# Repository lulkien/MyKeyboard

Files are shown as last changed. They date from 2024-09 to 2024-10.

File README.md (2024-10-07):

# My Custom Mechanical Keyboard

This is the design for my custom TLK, where I'm gonna make my own keyboard from scratch with hotswap controller.

(I have no idea why I'm doing this but it's kinda cool)

## Todo:

- [x] PCB Design (Kicad 8)
- [x] Case Design (OpenSCAD)
- [x] Firmware (use Rust)

## References:

- [Joe Scotto's guide for the PCB design](https://www.youtube.com/watch?v=7LyziNdFlew&list=PLBD2IS_t_iWZDMdG_ZF57x9Ebm3kxKqxF) (recommend to watch this playlist first)

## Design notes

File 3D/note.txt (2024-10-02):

pcb width: 295.275mm
pcb height: 152.4mm

plate to pcb: 3.5mm

plate slot:
    width: 152.4mm
    height: 1.5mm
    depth: 2mm

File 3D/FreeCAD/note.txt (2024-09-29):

Plate (
    geometry: [
        Rectangle (
            name: "USB in header",
            top: (44.7, 143.8),
            width: 5.8,
            height: 13.3,
        ),
        Rectangle (
            name: "Pico",
            top: (120.6, 148.7),
            width: 54.1,
            height: 24,1,
        ),
        Rectangle (
            name: "screen header",
            top: (253.3, 145.8),
            width: 13.3,
            header: 5.8,
        ),
    ],
)

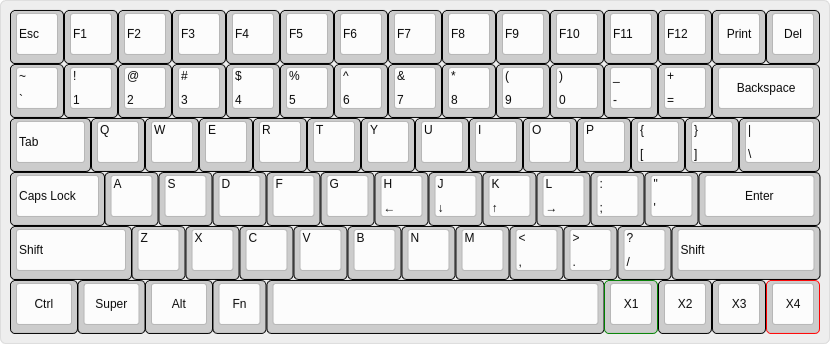
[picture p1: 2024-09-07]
layout/keyboard-layout.png

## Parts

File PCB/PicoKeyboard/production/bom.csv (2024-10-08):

Designator | Footprint | Quantity | Value | LCSC Part #
C1, C4 | 0603 | 2 | 100nF | C1591
C2, C3 | 0603 | 2 | 1uF | C15849
D1, D10, D11, D12, D13, D14, D15, D16, D17, D18, D19, D2, D20, D21, D22, D23, D24, D25, D26, D27, D28, D29, D3, D30, D31, D32, D33, D34, D35, D36, D37, D38, D39, D4, D40, D41, D42, D43, D44, D45, D46, D47, D48, D49, D5, D50, D51, D52, D53, D54, D55, D56, D57, D58, D59, D6, D60, D61, D62, D63, D64, D65, D66, D67, D68, D69, D7, D70, D71, D72, D73, D74, D75, D76, D77, D8, D9 | Diode_SOD-123 | 77 | Diode | C5119556
R1, R2 | 0603 | 2 | 5.1k | C23186

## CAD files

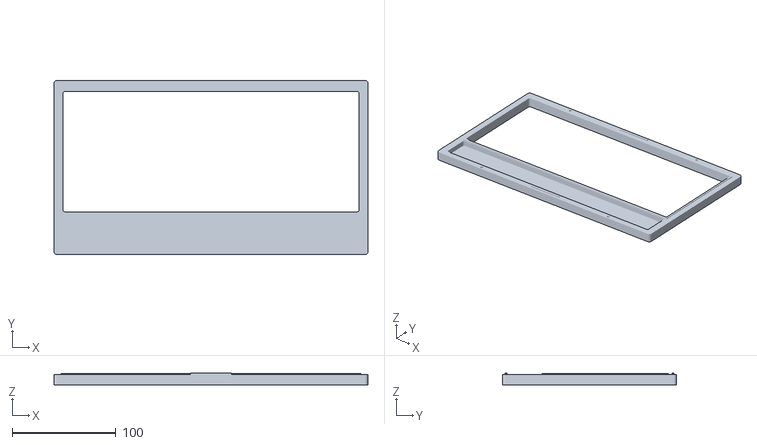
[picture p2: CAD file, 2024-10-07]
3D/export/top.stl
303.3 x 168.4 x 11.5

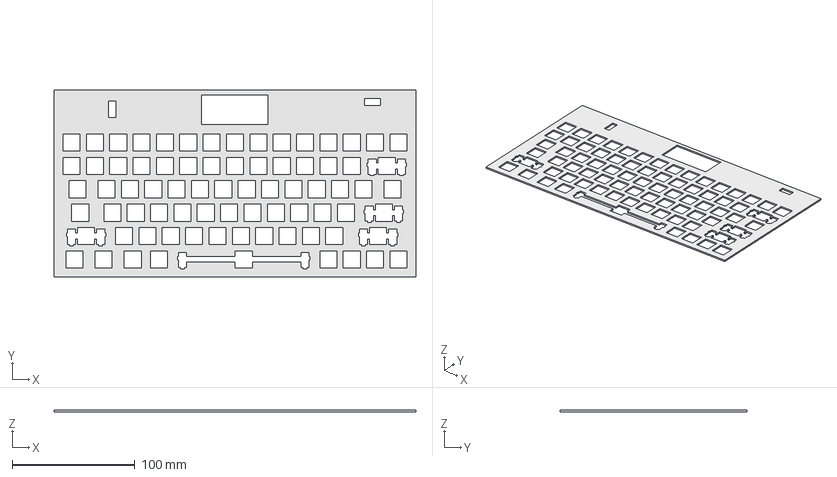
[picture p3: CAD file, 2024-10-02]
3D/FreeCAD/plate.FCStd
295.3 x 152.4 x 1.50 mm

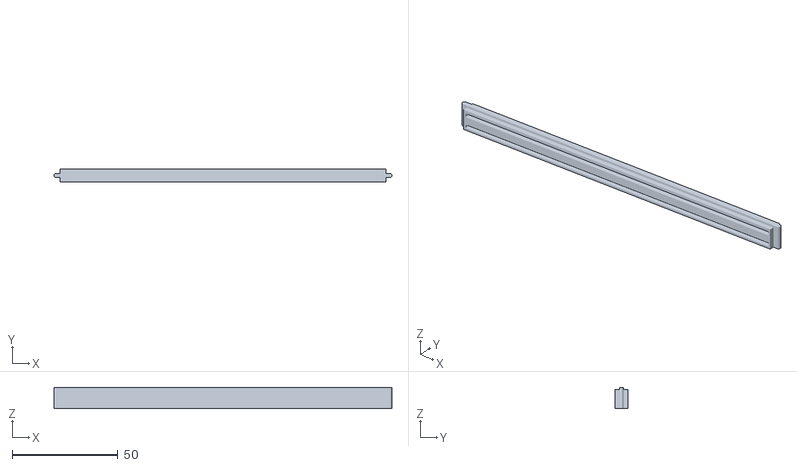
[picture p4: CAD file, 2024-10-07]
3D/export/side_bar.stl
160.0 x 6.00 x 10.0

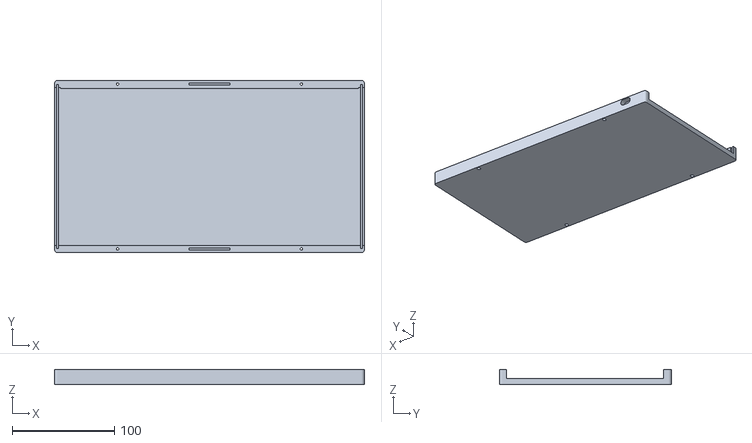
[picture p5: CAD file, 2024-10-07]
3D/export/bottom.stl
303.3 x 168.4 x 15.0

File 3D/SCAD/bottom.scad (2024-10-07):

module bottom_piece() {
    difference() {
        difference() {
            hull() {
                $fn = 200;
                border_rad = 3;
                width = 303.3;
                height = 168.4;
                depth = 15;
                
                pos_cylinder_x = width / 2 - border_rad;
                pos_cylinder_y = height / 2 - border_rad; 
                
                position = [
                    [pos_cylinder_x, pos_cylinder_y, 0],
                    [-pos_cylinder_x, pos_cylinder_y, 0],
                    [pos_cylinder_x, -pos_cylinder_y, 0],
                    [-pos_cylinder_x, -pos_cylinder_y, 0],
                ];
                
                for (pos = position) {
                    translate(pos)  cylinder(h = depth, r = border_rad, center = true);
                }
            }
            
            // main cut
            translate([0, -0.4, 3.5]) cube([400, 153.6, 10], center = true);
            
            // Side cut
            translate([149.1, 0, 3.5]) cube([7, 154.4, 10], center = true);
            translate([148.65, 0, 3]) cube([2, 160.4, 11], center = true);
            
            translate([-149.1, 0, 3.5]) cube([7, 154.4, 10], center = true);
            translate([-148.65, 0, 3]) cube([2, 160.4, 11], center = true);
        }
        
        // Screw holes
        // In bottom plate thread: 8mm
        // In top plate: 4mm
        
        screw_positions = [
            [90, 80.7, -1.5],
            [-90, 80.7, -1.5],
            [90, -80.7, -1.5],
            [-90, -80.7, -1.5],
        ];
        
        for (screw_pos = screw_positions) {
            translate(screw_pos) union() {
                $fn = 200;
                cylinder(h = 10, d = 2.51);
                translate([0, 0, -9]) cylinder(h = 10, d = 4.43);
            }
        }
        
        // Top piece mounting point
        translate([0, 80.7, 8]) cube([40, 2, 5], center = true);
        translate([0, -80.7, 8]) cube([40, 2, 5], center = true);
        
        // USB C socket
        translate([-123.1, 77.5, 2.9]) rotate([90, 90, 0]) union() {
            hull() {
                $fn=200;
                translate([0, 3.25, -10]) cylinder(30, d1=2.7, d2=2.7);
                translate([0, -3.25, -10]) cylinder(30, d1=2.7, d2=2.7);
            }
    
            hull() {
                $fn=200;
                translate([0, 3.25, -10]) cylinder(10, d1=7, d2=7);
                translate([0, -3.25, -10]) cylinder(10, d1=7, d2=7);
            }
        }
    }
}

bottom_piece();

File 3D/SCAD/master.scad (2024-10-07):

use <top.scad>
use <bottom.scad>
use <side_bar.scad>

rotate([0, 0, 0]) union() {
    translate([0, 0, 0]) bottom_piece();
    %translate([0, 0, 12.5]) top_piece();
    #translate([-148.65, 0, 3]) rotate([0, 0, -90]) side_bar();
    #translate([148.65, 0, 3]) rotate([0, 0, 90]) side_bar();
}


// export
//bottom_piece();

//rotate([180, 0, 0]) top_piece();

//rotate([180, 0, 0]) side_bar();

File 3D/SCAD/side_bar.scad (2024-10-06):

module side_bar() {    
    union() {
        // slots
        translate([0, 0, 3.5]) difference() {
            translate([0, 0, -3.5]) cube([154.4, 6, 9], center = true);
    
            // plate slot
            translate([0, 2.5, -0.75]) cube([152.4, 5, 1.5], center = true);
    
            // pcb slot
            translate([0, 2.5, 0.8 - 1.6 - 5]) cube([152.4, 5, 1.6], center = true);
        }
    
        // side bar
//        translate([0, 0, -0.5]) cube([160.4, 2, 10], center = true);
        translate([0, 0, -0.5]) hull() {
            $fn = 200;
            translate([79, 0, 0]) cylinder(h = 10, r = 1, center = true);
            translate([-79, 0, 0]) cylinder(h = 10, r = 1, center = true);
        }
    }
}

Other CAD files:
3D/SCAD/top.scad
3D/FreeCAD/plate.dxf
3D/export/plate.stl

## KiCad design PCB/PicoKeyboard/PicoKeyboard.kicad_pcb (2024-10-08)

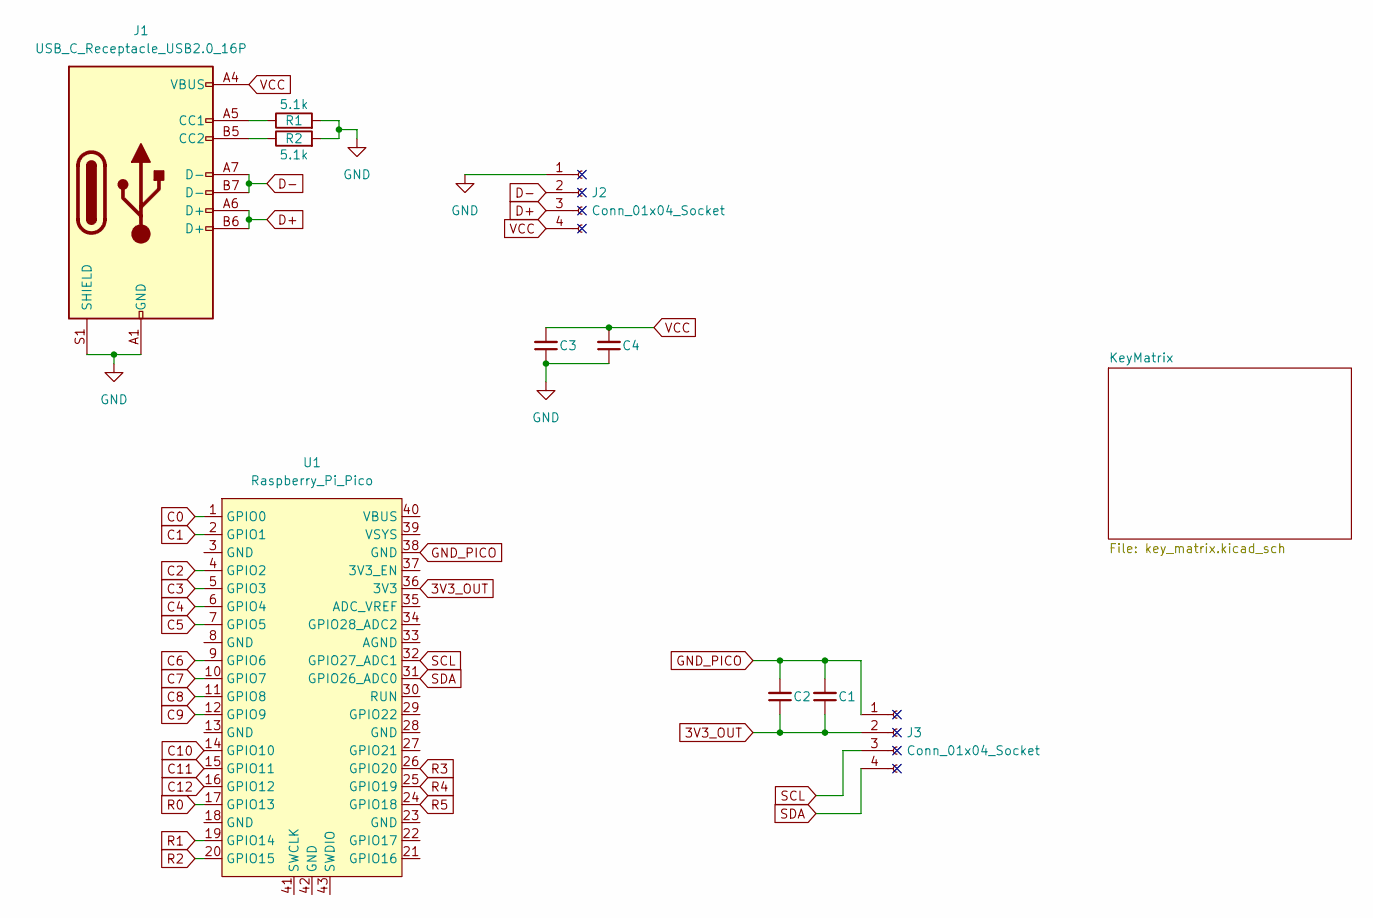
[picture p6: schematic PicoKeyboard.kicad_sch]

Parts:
C1, C4: 100nF; C_0603_1608Metric
C2, C3: 1uF; C_0603_1608Metric
J1: USB_C_Receptacle_USB2.0_16P; USB_C_Receptacle_HCTL_HC-TYPE-C-16P-01A
J2: Conn_01x04_Socket; PinHeader_1x04_P2.54mm_Vertical
J3: Conn_01x04_Socket; PinSocket_1x04_P2.54mm_Vertical
R1, R2: 5.1k; R_0603_1608Metric
U1: Raspberry_Pi_Pico

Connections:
3V3_OUT: C1.1, C2.1, J3.2, U1.36 (3V3)
C0: U1.1 (GPIO0); also elsewhere on the board
C1: U1.2 (GPIO1); also elsewhere on the board
C2: U1.4 (GPIO2); also elsewhere on the board
C3: U1.5 (GPIO3); also elsewhere on the board
C4: U1.6 (GPIO4); also elsewhere on the board
C5: U1.7 (GPIO5); also elsewhere on the board
C6: U1.9 (GPIO6); also elsewhere on the board
C7: U1.10 (GPIO7); also elsewhere on the board
C8: U1.11 (GPIO8); also elsewhere on the board
C9: U1.12 (GPIO9); also elsewhere on the board
C10: U1.14 (GPIO10); also elsewhere on the board
C11: U1.15 (GPIO11); also elsewhere on the board
C12: U1.16 (GPIO12); also elsewhere on the board
D+: J1.A6 (D+), J1.B6 (D+), J2.3
D-: J1.A7 (D-), J1.B7 (D-), J2.2
GND: C3.1, C4.1, J1.A1 (GND), J1.A12 (GND), J1.B1 (GND), J1.B12 (GND), J1.S1 (SHIELD), J2.1, R1.2, R2.2
GND_PICO: C1.2, C2.2, J3.1, U1.38 (GND)
unnamed: J1.A5 (CC1), R1.1
unnamed: J1.B5 (CC2), R2.1
R0: U1.17 (GPIO13); also elsewhere on the board
R1: U1.19 (GPIO14); also elsewhere on the board
R2: U1.20 (GPIO15); also elsewhere on the board
R3: U1.26 (GPIO20); also elsewhere on the board
R4: U1.25 (GPIO19); also elsewhere on the board
R5: U1.24 (GPIO18); also elsewhere on the board
SCL: J3.3, U1.32 (GPIO27_ADC1)
SDA: J3.4, U1.31 (GPIO26_ADC0)
VCC: C3.2, C4.2, J1.A4 (VBUS), J1.A9 (VBUS), J1.B4 (VBUS), J1.B9 (VBUS), J2.4

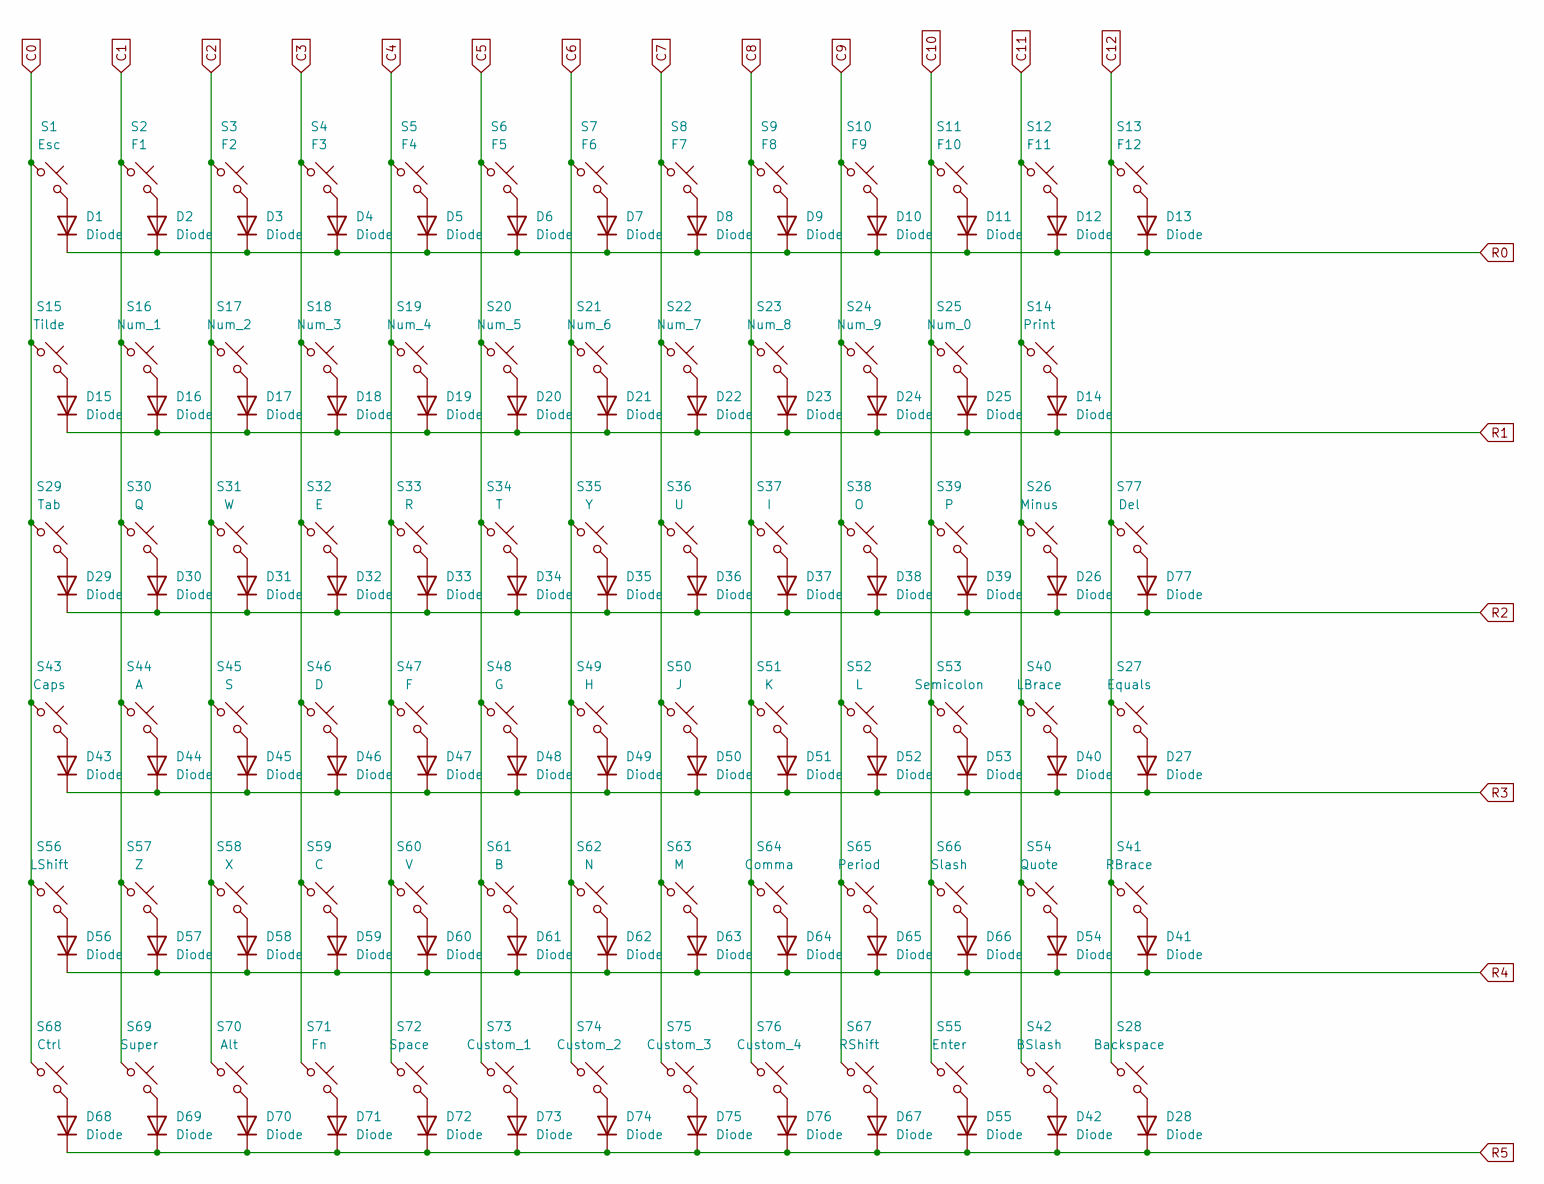
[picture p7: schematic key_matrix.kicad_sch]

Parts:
D1, D2, D3, D4, D5, D6, D7, D8, D9, D10, D11, D12, D13, D14, D15, D16, D17, D18, D19, D20, D21, D22, D23, D24, D25, D26, D27, D28, D29, D30, D31, D32, D33, D34, D35, D36, D37, D38, D39, D40, D41, D42, D43, D44, D45, D46, D47, D48, D49, D50, D51, D52, D53, D54, D55, D56, D57, D58, D59, D60, D61, D62, D63, D64, D65, D66, D67, D68, D69, D70, D71, D72, D73, D74, D75, D76, D77: Diode; Diode_SOD-123
S1: Esc; Hotswap_MX_1.00u
S2: F1; Hotswap_MX_1.00u
S3: F2; Hotswap_MX_1.00u
S4: F3; Hotswap_MX_1.00u
S5: F4; Hotswap_MX_1.00u
S6: F5; Hotswap_MX_1.00u
S7: F6; Hotswap_MX_1.00u
S8: F7; Hotswap_MX_1.00u
S9: F8; Hotswap_MX_1.00u
S10: F9; Hotswap_MX_1.00u
S11: F10; Hotswap_MX_1.00u
S12: F11; Hotswap_MX_1.00u
S13: F12; Hotswap_MX_1.00u
S14: Print; Hotswap_MX_1.00u
S15: Tilde; Hotswap_MX_1.00u
S16: Num_1; Hotswap_MX_1.00u
S17: Num_2; Hotswap_MX_1.00u
S18: Num_3; Hotswap_MX_1.00u
S19: Num_4; Hotswap_MX_1.00u
S20: Num_5; Hotswap_MX_1.00u
S21: Num_6; Hotswap_MX_1.00u
S22: Num_7; Hotswap_MX_1.00u
S23: Num_8; Hotswap_MX_1.00u
S24: Num_9; Hotswap_MX_1.00u
S25: Num_0; Hotswap_MX_1.00u
S26: Minus; Hotswap_MX_1.00u
S27: Equals; Hotswap_MX_1.00u
S28: Backspace; Hotswap_MX_2.00u
S29: Tab; Hotswap_MX_1.50u
S30: Q; Hotswap_MX_1.00u
S31: W; Hotswap_MX_1.00u
S32: E; Hotswap_MX_1.00u
S33: R; Hotswap_MX_1.00u
S34: T; Hotswap_MX_1.00u
S35: Y; Hotswap_MX_1.00u
S36: U; Hotswap_MX_1.00u
S37: I; Hotswap_MX_1.00u
S38: O; Hotswap_MX_1.00u
S39: P; Hotswap_MX_1.00u
S40: LBrace; Hotswap_MX_1.00u
S41: RBrace; Hotswap_MX_1.00u
S42: BSlash; Hotswap_MX_1.50u
S43: Caps; Hotswap_MX_1.75u
S44: A; Hotswap_MX_1.00u
S45: S; Hotswap_MX_1.00u
S46: D; Hotswap_MX_1.00u
S47: F; Hotswap_MX_1.00u
S48: G; Hotswap_MX_1.00u
S49: H; Hotswap_MX_1.00u
S50: J; Hotswap_MX_1.00u
S51: K; Hotswap_MX_1.00u
S52: L; Hotswap_MX_1.00u
S53: Semicolon; Hotswap_MX_1.00u
S54: Quote; Hotswap_MX_1.00u
S55: Enter; Hotswap_MX_2.25u
S56: LShift; Hotswap_MX_2.25u
S57: Z; Hotswap_MX_1.00u
S58: X; Hotswap_MX_1.00u
S59: C; Hotswap_MX_1.00u
S60: V; Hotswap_MX_1.00u
S61: B; Hotswap_MX_1.00u
S62: N; Hotswap_MX_1.00u
S63: M; Hotswap_MX_1.00u
S64: Comma; Hotswap_MX_1.00u
S65: Period; Hotswap_MX_1.00u
S66: Slash; Hotswap_MX_1.00u
S67: RShift; Hotswap_MX_2.75u
S68: Ctrl; Hotswap_MX_1.25u
S69: Super; Hotswap_MX_1.25u
S70: Alt; Hotswap_MX_1.25u
S71: Fn; Hotswap_MX_1.00u
S72: Space; Hotswap_MX_6.25u
S73: Custom_1; Hotswap_MX_1.00u
S74: Custom_2; Hotswap_MX_1.00u
S75: Custom_3; Hotswap_MX_1.00u
S76: Custom_4; Hotswap_MX_1.00u
S77: Del; Hotswap_MX_1.00u

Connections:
C0: S1.1, S15.1, S29.1, S43.1, S56.1, S68.1; also elsewhere on the board
C1: S2.1, S16.1, S30.1, S44.1, S57.1, S69.1; also elsewhere on the board
C2: S3.1, S17.1, S31.1, S45.1, S58.1, S70.1; also elsewhere on the board
C3: S4.1, S18.1, S32.1, S46.1, S59.1, S71.1; also elsewhere on the board
C4: S5.1, S19.1, S33.1, S47.1, S60.1, S72.1; also elsewhere on the board
C5: S6.1, S20.1, S34.1, S48.1, S61.1, S73.1; also elsewhere on the board
C6: S7.1, S21.1, S35.1, S49.1, S62.1, S74.1; also elsewhere on the board
C7: S8.1, S22.1, S36.1, S50.1, S63.1, S75.1; also elsewhere on the board
C8: S9.1, S23.1, S37.1, S51.1, S64.1, S76.1; also elsewhere on the board
C9: S10.1, S24.1, S38.1, S52.1, S65.1, S67.1; also elsewhere on the board
C10: S11.1, S25.1, S39.1, S53.1, S55.1, S66.1; also elsewhere on the board
C11: S12.1, S14.1, S26.1, S40.1, S42.1, S54.1; also elsewhere on the board
C12: S13.1, S27.1, S28.1, S41.1, S77.1; also elsewhere on the board
unnamed: D1.2 (A), S1.2
unnamed: D2.2 (A), S2.2
unnamed: D3.2 (A), S3.2
unnamed: D4.2 (A), S4.2
unnamed: D5.2 (A), S5.2
unnamed: D6.2 (A), S6.2
unnamed: D7.2 (A), S7.2
unnamed: D8.2 (A), S8.2
unnamed: D9.2 (A), S9.2
unnamed: D10.2 (A), S10.2
unnamed: D11.2 (A), S11.2
unnamed: D12.2 (A), S12.2
unnamed: D13.2 (A), S13.2
unnamed: D14.2 (A), S14.2
unnamed: D15.2 (A), S15.2
unnamed: D16.2 (A), S16.2
unnamed: D17.2 (A), S17.2
unnamed: D18.2 (A), S18.2
unnamed: D19.2 (A), S19.2
unnamed: D20.2 (A), S20.2
unnamed: D21.2 (A), S21.2
unnamed: D22.2 (A), S22.2
unnamed: D23.2 (A), S23.2
unnamed: D24.2 (A), S24.2
unnamed: D25.2 (A), S25.2
unnamed: D26.2 (A), S26.2
unnamed: D27.2 (A), S27.2
unnamed: D28.2 (A), S28.2
unnamed: D29.2 (A), S29.2
unnamed: D30.2 (A), S30.2
unnamed: D31.2 (A), S31.2
unnamed: D32.2 (A), S32.2
unnamed: D33.2 (A), S33.2
unnamed: D34.2 (A), S34.2
unnamed: D35.2 (A), S35.2
unnamed: D36.2 (A), S36.2
unnamed: D37.2 (A), S37.2
unnamed: D38.2 (A), S38.2
unnamed: D39.2 (A), S39.2
unnamed: D40.2 (A), S40.2
unnamed: D41.2 (A), S41.2
unnamed: D42.2 (A), S42.2
unnamed: D43.2 (A), S43.2
unnamed: D44.2 (A), S44.2
unnamed: D45.2 (A), S45.2
unnamed: D46.2 (A), S46.2
unnamed: D47.2 (A), S47.2
unnamed: D48.2 (A), S48.2
unnamed: D49.2 (A), S49.2
unnamed: D50.2 (A), S50.2
unnamed: D51.2 (A), S51.2
unnamed: D52.2 (A), S52.2
unnamed: D53.2 (A), S53.2
unnamed: D54.2 (A), S54.2
unnamed: D55.2 (A), S55.2
unnamed: D56.2 (A), S56.2
unnamed: D57.2 (A), S57.2
unnamed: D58.2 (A), S58.2
unnamed: D59.2 (A), S59.2
unnamed: D60.2 (A), S60.2
unnamed: D61.2 (A), S61.2
unnamed: D62.2 (A), S62.2
unnamed: D63.2 (A), S63.2
unnamed: D64.2 (A), S64.2
unnamed: D65.2 (A), S65.2
unnamed: D66.2 (A), S66.2
unnamed: D67.2 (A), S67.2
unnamed: D68.2 (A), S68.2
unnamed: D69.2 (A), S69.2
unnamed: D70.2 (A), S70.2
unnamed: D71.2 (A), S71.2
unnamed: D72.2 (A), S72.2
unnamed: D73.2 (A), S73.2
unnamed: D74.2 (A), S74.2
unnamed: D75.2 (A), S75.2
unnamed: D76.2 (A), S76.2
unnamed: D77.2 (A), S77.2
R0: D1.1 (K), D2.1 (K), D3.1 (K), D4.1 (K), D5.1 (K), D6.1 (K), D7.1 (K), D8.1 (K), D9.1 (K), D10.1 (K), D11.1 (K), D12.1 (K), D13.1 (K); also elsewhere on the board
R1: D14.1 (K), D15.1 (K), D16.1 (K), D17.1 (K), D18.1 (K), D19.1 (K), D20.1 (K), D21.1 (K), D22.1 (K), D23.1 (K), D24.1 (K), D25.1 (K); also elsewhere on the board
R2: D26.1 (K), D29.1 (K), D30.1 (K), D31.1 (K), D32.1 (K), D33.1 (K), D34.1 (K), D35.1 (K), D36.1 (K), D37.1 (K), D38.1 (K), D39.1 (K), D77.1 (K); also elsewhere on the board
R3: D27.1 (K), D40.1 (K), D43.1 (K), D44.1 (K), D45.1 (K), D46.1 (K), D47.1 (K), D48.1 (K), D49.1 (K), D50.1 (K), D51.1 (K), D52.1 (K), D53.1 (K); also elsewhere on the board
R4: D41.1 (K), D54.1 (K), D56.1 (K), D57.1 (K), D58.1 (K), D59.1 (K), D60.1 (K), D61.1 (K), D62.1 (K), D63.1 (K), D64.1 (K), D65.1 (K), D66.1 (K); also elsewhere on the board
R5: D28.1 (K), D42.1 (K), D55.1 (K), D67.1 (K), D68.1 (K), D69.1 (K), D70.1 (K), D71.1 (K), D72.1 (K), D73.1 (K), D74.1 (K), D75.1 (K), D76.1 (K); also elsewhere on the board

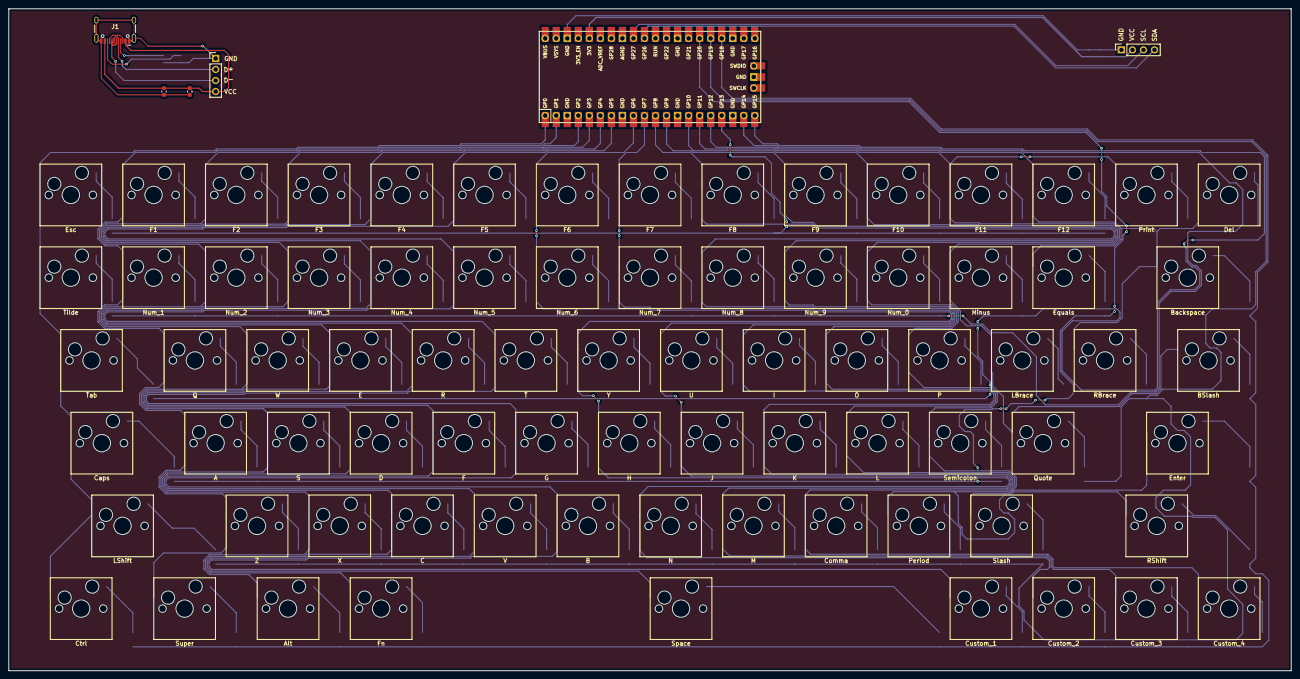
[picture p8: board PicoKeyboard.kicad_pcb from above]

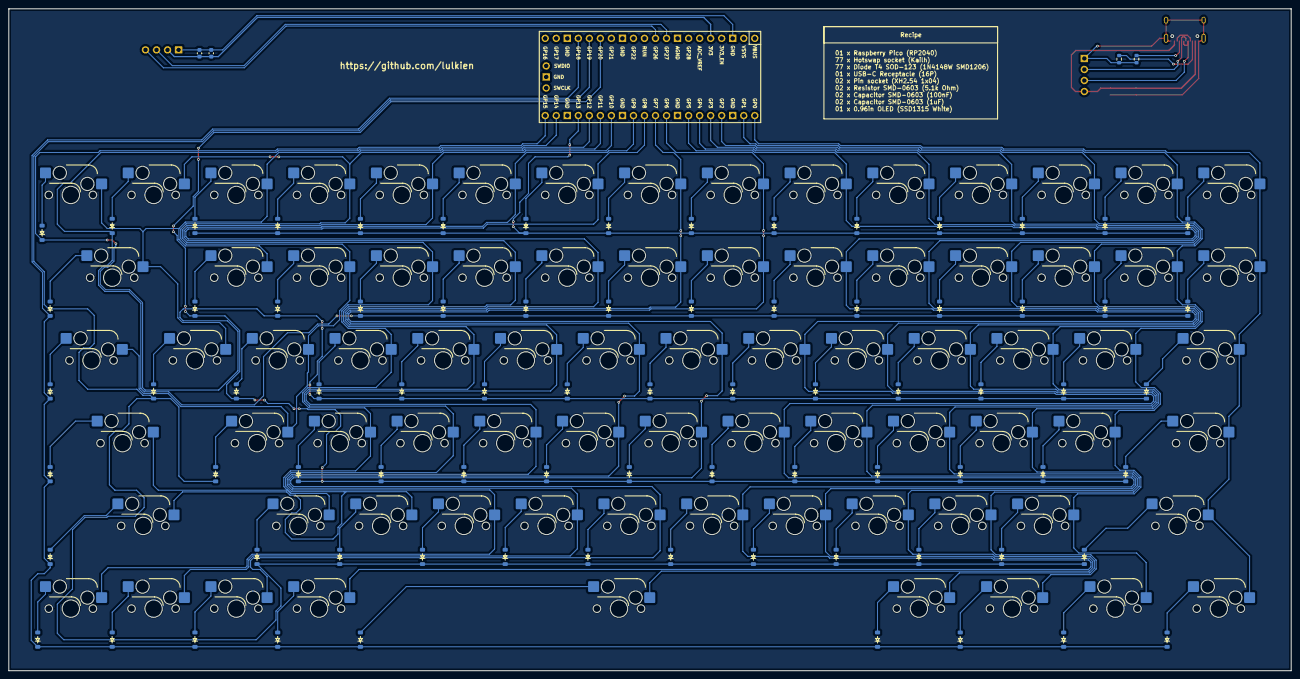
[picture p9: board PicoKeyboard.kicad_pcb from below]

Board: 2 copper layers, 295.3 x 152.4 mm, 164 parts (81 on the bottom side), 106 nets.

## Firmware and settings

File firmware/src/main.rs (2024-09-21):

// Simple keyboard firmware. Inspired by the RustyKeys project:
// https://github.com/KOBA789/rusty-keys/blob/main/firmware/keyboard/src/bin/simple.rs

#![no_main]
#![no_std]

mod debounce;
mod hid_class;
mod hid_descriptor;
mod key_codes;
mod key_mapping;
mod key_scan;

use crate::{
    hid_class::HidClass,
    key_scan::{KeyboardReport, TRANSPOSED_NORMAL_LAYER_MAPPING},
};
use core::{cell::RefCell, convert::Infallible};
use cortex_m::prelude::_embedded_hal_timer_CountDown;
use critical_section::Mutex;
use debounce::Debounce;
use defmt::{error, info, warn};
use defmt_rtt as _;
use embedded_hal::digital::{InputPin, OutputPin};
use fugit::ExtU32;
use key_scan::KeyScan;
use panic_probe as _;
use rp2040_hal::{
    pac::{self, interrupt},
    usb::{self, UsbBus},
    Clock, Watchdog,
};
use usb_device::{bus::UsbBusAllocator, device::UsbDeviceBuilder, prelude::*};

/// The rate of polling of the keyboard itself in firmware.
const SCAN_LOOP_RATE_MS: u32 = 1;
/// The number of milliseconds to wait until a "key-off-then-key-on" in quick succession is allowed.
const DEBOUNCE_MS: u8 = 6;

const DEBOUNCE_TICKS: u8 = DEBOUNCE_MS / (SCAN_LOOP_RATE_MS as u8);

/// The linker will place this boot block at the start of our program image. We
/// need this to help the ROM bootloader get our code up and running.
#[link_section = ".boot2"]
#[used]
pub static BOOT2: [u8; 256] = rp2040_boot2::BOOT_LOADER_W25Q080;

const NUM_COLS: usize = 13;
const NUM_ROWS: usize = 6;

const EXTERNAL_CRYSTAL_FREQUENCY_HZ: u32 = 12_000_000;

/// The USB Device Driver (shared with the interrupt).
static mut USB_DEVICE: Option<UsbDevice<usb::UsbBus>> = None;

/// The USB Bus Driver (shared with the interrupt).
static mut USB_BUS: Option<UsbBusAllocator<usb::UsbBus>> = None;

/// The USB Human Interface Device Driver (shared with the interrupt).
static USB_HID_CLASS: Mutex<RefCell<Option<HidClass<usb::UsbBus>>>> =
    Mutex::new(RefCell::new(None));

#[defmt::panic_handler]
fn panic() -> ! {
    cortex_m::asm::udf()
}

#[cortex_m_rt::entry]
fn main() -> ! {
    info!("Start of main()");
    let mut pac = pac::Peripherals::take().unwrap();
    let core = pac::CorePeripherals::take().unwrap();

    let mut watchdog = Watchdog::new(pac.WATCHDOG);

    let clocks = rp2040_hal::clocks::init_clocks_and_plls(
        EXTERNAL_CRYSTAL_FREQUENCY_HZ,
        pac.XOSC,
        pac.CLOCKS,
        pac.PLL_SYS,
        pac.PLL_USB,
        &mut pac.RESETS,
        &mut watchdog,
    )
    .ok()
    .unwrap();

    // Get the GPIO peripherals.
    let sio = rp2040_hal::Sio::new(pac.SIO);

    let pins =
        rp2040_hal::gpio::Pins::new(pac.IO_BANK0, pac.PADS_BANK0, sio.gpio_bank0, &mut pac.RESETS);

    // Set up keyboard matrix pins.
    let mut rows: [&mut dyn InputPin<Error = Infallible>; NUM_ROWS] = [
        &mut pins.gpio13.into_pull_down_input(),
        &mut pins.gpio14.into_pull_down_input(),
        &mut pins.gpio15.into_pull_down_input(),
        &mut pins.gpio20.into_pull_down_input(),
        &mut pins.gpio19.into_pull_down_input(),
        &mut pins.gpio18.into_pull_down_input(),
    ];

    let mut cols: [&mut dyn OutputPin<Error = Infallible>; NUM_COLS] = [
        &mut pins.gpio0.into_push_pull_output(),
        &mut pins.gpio1.into_push_pull_output(),
        &mut pins.gpio2.into_push_pull_output(),
        &mut pins.gpio3.into_push_pull_output(),
        &mut pins.gpio4.into_push_pull_output(),
        &mut pins.gpio5.into_push_pull_output(),
        &mut pins.gpio6.into_push_pull_output(),
        &mut pins.gpio7.into_push_pull_output(),
        &mut pins.gpio8.into_push_pull_output(),
        &mut pins.gpio9.into_push_pull_output(),
        &mut pins.gpio10.into_push_pull_output(),
        &mut pins.gpio11.into_push_pull_output(),
        &mut pins.gpio12.into_push_pull_output(),
    ];

    // Initialize a delay for accurate sleeping.
    let mut delay = cortex_m::delay::Delay::new(core.SYST, clocks.system_clock.freq().to_Hz());
    let timer = rp2040_hal::Timer::new(pac.TIMER, &mut pac.RESETS, &clocks);

    let mut modifier_mask = [[false; NUM_ROWS]; NUM_COLS];
    for (col, mapping_col) in modifier_mask.iter_mut().zip(TRANSPOSED_NORMAL_LAYER_MAPPING) {
        for (key, mapping_key) in col.iter_mut().zip(mapping_col) {
            *key = mapping_key.is_modifier();
        }
    }

    // Create a global debounce state to prevent unintended rapid key double-presses.
    let mut debounce: Debounce<NUM_ROWS, NUM_COLS> = Debounce::new(DEBOUNCE_TICKS, modifier_mask);

    // Do an initial scan of the keys so that we immediately have something to report to the host when asked.
    let scan = KeyScan::scan(&mut rows, &mut cols, &mut delay, &mut debounce);

    // If the Escape key is pressed during power-on, we should go into bootloader mode.
    if scan[0][0] {
        let gpio_activity_pin_mask = 0;
        let disable_interface_mask = 0;
        info!("Escape key detected on boot, going into bootloader mode.");
        rp2040_hal::rom_data::reset_to_usb_boot(gpio_activity_pin_mask, disable_interface_mask);
    }

    info!("Initializing USB");
    // Initialize USB
    let force_vbus_detect_bit = true;
    let usb_bus = UsbBus::new(
        pac.USBCTRL_REGS,
        pac.USBCTRL_DPRAM,
        clocks.usb_clock,
        force_vbus_detect_bit,
        &mut pac.RESETS,
    );
    let bus_allocator = UsbBusAllocator::new(usb_bus);
    let bus_allocator_ref = unsafe {
        // Note (safety): This is safe as interrupts haven't been started yet
        USB_BUS = Some(bus_allocator);
        // We are promising to the compiler not to take mutable access to this global
        // variable while this reference exists!
        USB_BUS.as_ref().unwrap()
    };

    let hid_class = HidClass::new(bus_allocator_ref);

    // https://github.com/obdev/v-usb/blob/7a28fdc685952412dad2b8842429127bc1cf9fa7/usbdrv/USB-IDs-for-free.txt#L128
    let keyboard_usb_device = UsbDeviceBuilder::new(bus_allocator_ref, UsbVidPid(0x16c0, 0x27db))
        .supports_remote_wakeup(true)
        .strings(&[StringDescriptors::default().manufacturer("bschwind").product("key ripper")])
        .unwrap()
        .build();

    unsafe {
        // Note (safety): This is safe as interrupts haven't been started yet
        critical_section::with(|cs| {
            USB_HID_CLASS.replace(cs, Some(hid_class));
        });

        USB_DEVICE = Some(keyboard_usb_device);
    }
    info!("Enabling USB interrupt handler");
    unsafe {
        pac::NVIC::unmask(pac::Interrupt::USBCTRL_IRQ);
    }
    info!("Entering main loop");

    let mut tick_count_down = timer.count_down();
    tick_count_down.start(1.millis());

    let mut last_report: KeyboardReport = scan.into();

    loop {
        if tick_count_down.wait().is_ok() {
            let scan = KeyScan::scan(&mut rows, &mut cols, &mut delay, &mut debounce);
            let report: KeyboardReport = scan.into();

            if report != last_report {
                critical_section::with(|cs| {
                    let mut hid_class = USB_HID_CLASS.borrow_ref_mut(cs);
                    let hid_class = hid_class.as_mut().unwrap();

                    if let Err(err) = hid_class.write_raw_report(&report.as_raw_input()) {
                        match err {
                            UsbError::WouldBlock => warn!("UsbError::WouldBlock"),
                            UsbError::ParseError => error!("UsbError::ParseError"),
                            UsbError::BufferOverflow => error!("UsbError::BufferOverflow"),
                            UsbError::EndpointOverflow => error!("UsbError::EndpointOverflow"),
                            UsbError::EndpointMemoryOverflow => {
                                error!("UsbError::EndpointMemoryOverflow")
                            },
                            UsbError::InvalidEndpoint => error!("UsbError::InvalidEndpoint"),
                            UsbError::Unsupported => error!("UsbError::Unsupported"),
                            UsbError::InvalidState => error!("UsbError::InvalidState"),
                        }
                    } else {
                        // Only assign to last_report if it was successfully reported.
                        last_report = report;
                    }
                });
            }
        }
    }
}

/// Handle USB interrupts
#[allow(non_snake_case)]
#[interrupt]
unsafe fn USBCTRL_IRQ() {
    let usb_dev = USB_DEVICE.as_mut().unwrap();

    critical_section::with(|cs| {
        let mut hid_class = USB_HID_CLASS.borrow_ref_mut(cs);
        let hid_class = hid_class.as_mut().unwrap();

        usb_dev.poll(&mut [hid_class]);
    });
}

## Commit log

2024-05-16 Update gitignore for kicad and init commit kicad
    TODO: Add footprint for diode and wire the PCB
    [PicoKeyboard.kicad_pcb, PicoKeyboard.kicad_sch, key_matrix.kicad_sch]
2024-05-18 Completed prototype design for my custom keyboard
    [PicoKeyboard.kicad_pcb, PicoKeyboard.kicad_sch]
2024-05-19 Update PCB
    [PicoKeyboard.kicad_pcb]
2024-08-23 New layout
    [PicoKeyboard.kicad_pcb, PicoKeyboard.kicad_sch, key_matrix.kicad_sch]
2024-08-24 Complete wiring
    [PicoKeyboard.kicad_pcb, PicoKeyboard.kicad_sch]
2024-09-07 Change layout
    [PicoKeyboard.kicad_pcb, PicoKeyboard.kicad_sch, key_matrix.kicad_sch]
2024-09-08 Add Usb C header and XH 2.54 header
    [PicoKeyboard.kicad_pcb, PicoKeyboard.kicad_sch]
2024-09-08 Add early plate design
    [plate.dxf]
2024-09-09 Change gpio pin
    [PicoKeyboard.kicad_pcb, PicoKeyboard.kicad_sch]
2024-09-09 Add screen header pin
    [PicoKeyboard.kicad_pcb, PicoKeyboard.kicad_sch]
2024-09-21 Add firmware
    [PicoKeyboard.kicad_pcb, key_matrix.kicad_sch, plate.dxf]
2024-09-22 Update plate design
    [plate.dxf]
2024-09-26 Add production file
    [bom.csv, positions.csv]
2024-09-28 Plate model completed
    [design.FCStd, plate.dxf, plate.stl]
2024-09-29 Plate model completed 2
    [design.FCStd, plate.stl]
2024-10-02 Create side bar for plate and PCB holder
    [design.FCStd, plate.FCStd, side_bar.scad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]
2024-10-03 Update size bar
    [side_bar.scad, side_bar.stl]
2024-10-03 Add bottom part
    [bottom.scad, bottom.stl]
2024-10-06 Update design
    [PicoKeyboard.kicad_pcb, PicoKeyboard.kicad_sch, bottom.scad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]
2024-10-06 Completed bottom piece
    [bottom.scad, bottom.stl]
2024-10-06 Conmpleted design
    [PicoKeyboard.kicad_pcb, bom.csv, bottom.scad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]
2024-10-06 Completed design
    [bottom.scad, bottom.stl, master.scad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]
2024-10-06 Update 3d design
    [master.scad, top.scad, top.stl]
2024-10-07 Update PCB Production
    [bom.csv, positions.csv]
2024-10-07 Update BOM
    [bom.csv]
